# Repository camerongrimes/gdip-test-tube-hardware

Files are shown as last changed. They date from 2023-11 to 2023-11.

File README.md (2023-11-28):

# GDIP Test Tube Hardware

Controller for AL5D Lynxmotion robotic arm.

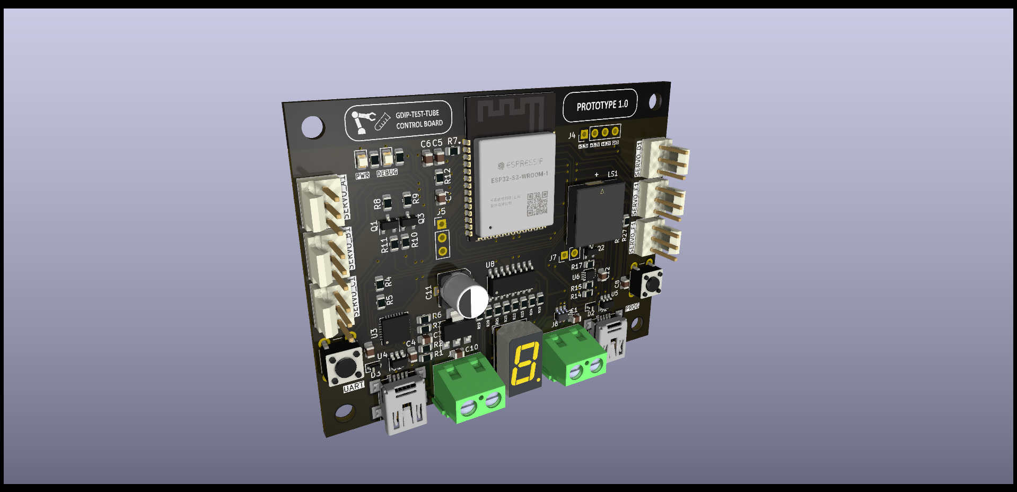
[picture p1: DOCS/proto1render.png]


## Features

- Webpage based more control using WiFi from the ESP32.
- Six servo outputs for control of all AL5D servos.
- Buzzer used to warn user that robotic arm is about to move.
- Seven segment display for error codes.
- Extra screw terminal for control of safety lightings around the arm.

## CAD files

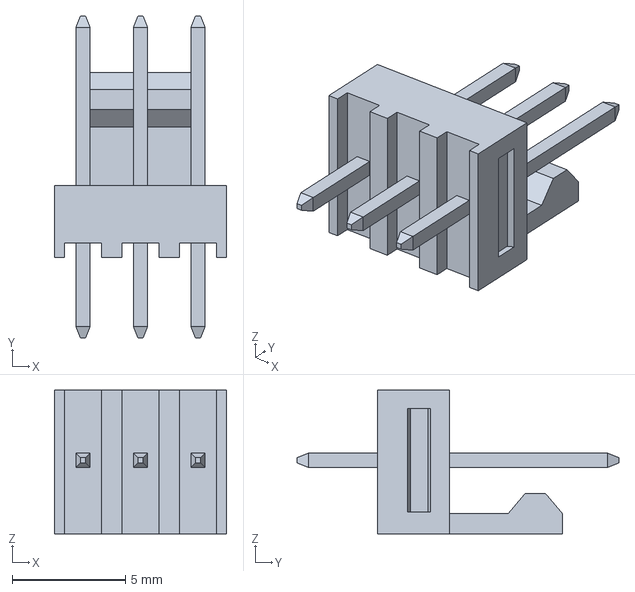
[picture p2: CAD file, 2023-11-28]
3D_MODELS/22-23-2031.stp
7.62 x 14.2 x 6.35 mm

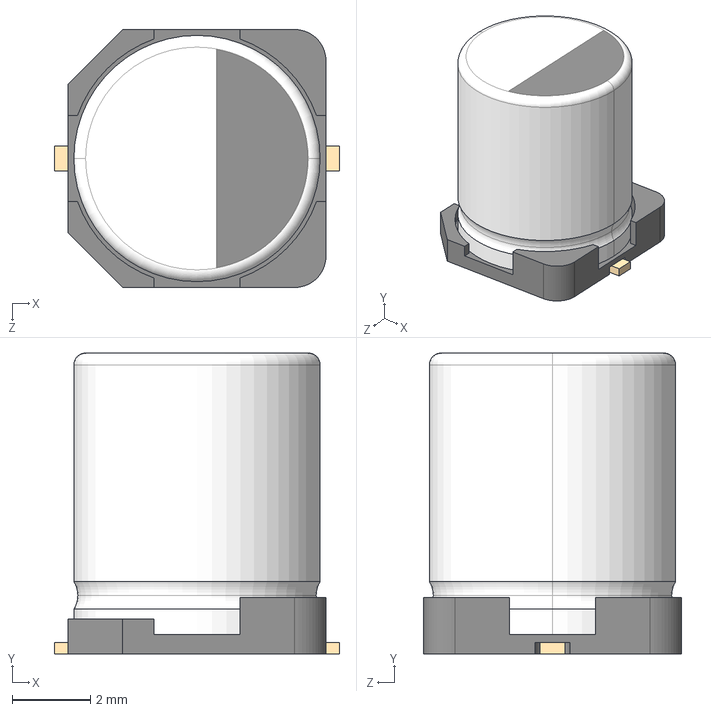
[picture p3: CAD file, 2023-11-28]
3D_MODELS/EEE-HA1H470XP.STEP
7.30 x 7.70 x 6.60 mm

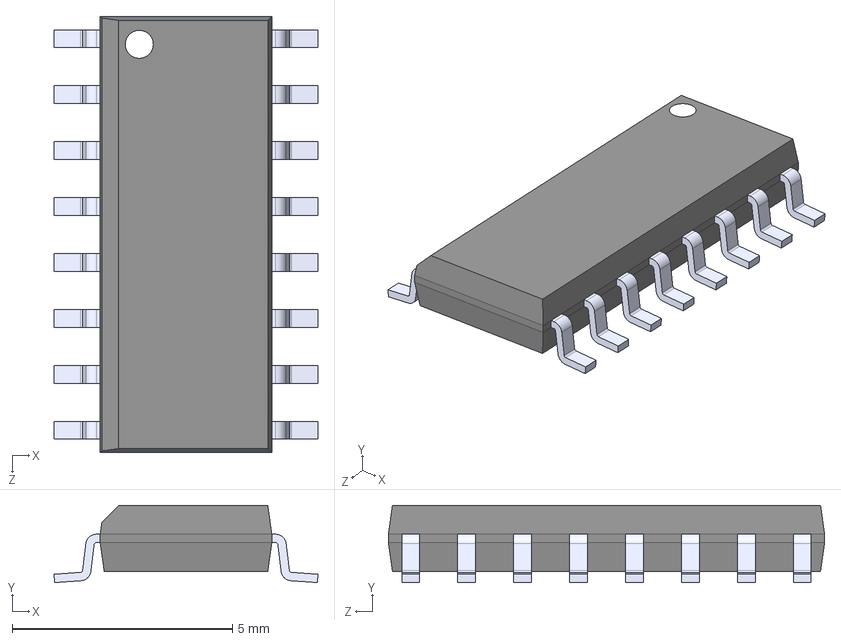
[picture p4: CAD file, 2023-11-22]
3D_MODELS/CD4543BM96.STEP
5.99 x 1.75 x 9.91 mm

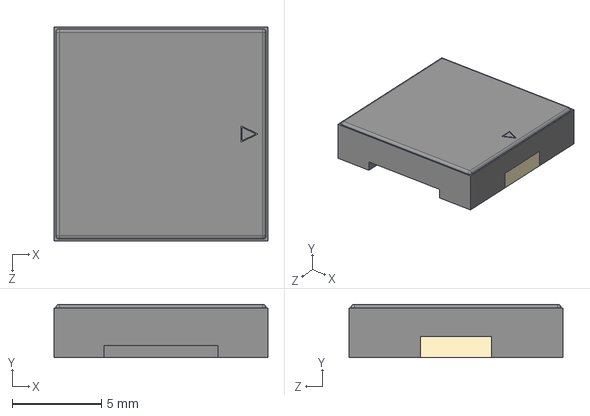
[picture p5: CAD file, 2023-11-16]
3D_MODELS/PKLCS1212E40A1-R1.STEP
12.0 x 3.00 x 12.0 mm

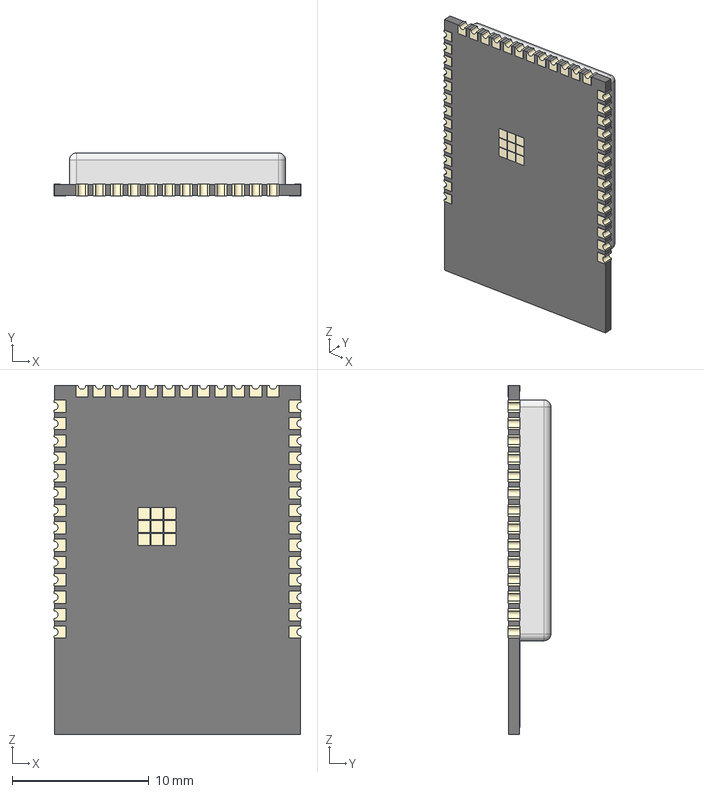
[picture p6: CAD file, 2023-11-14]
3D_MODELS/ESP32-S3-WROOM.step
18.0 x 3.16 x 25.5 mm
ESP-S3-WROOM_via x 26
ESP32-S3-WROOM_shell
ESP32-S3-WROOM_body
ESP-S3-WROOM_via v3(镜像) x 14

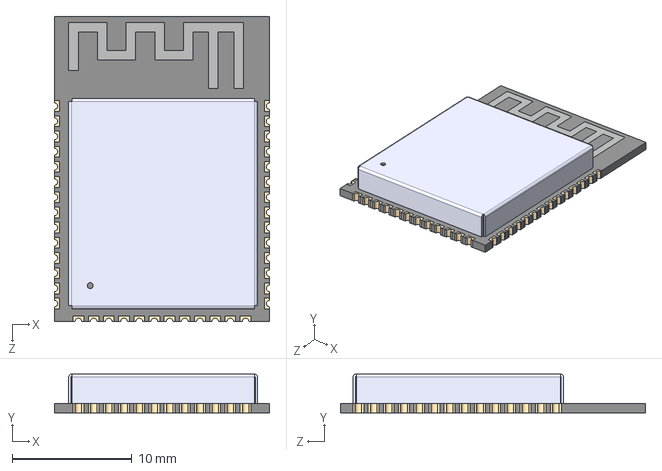
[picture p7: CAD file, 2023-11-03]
3D_MODELS/ESP32-S3-WROOM-1-N16R2.step
18.0 x 3.25 x 25.5 mm

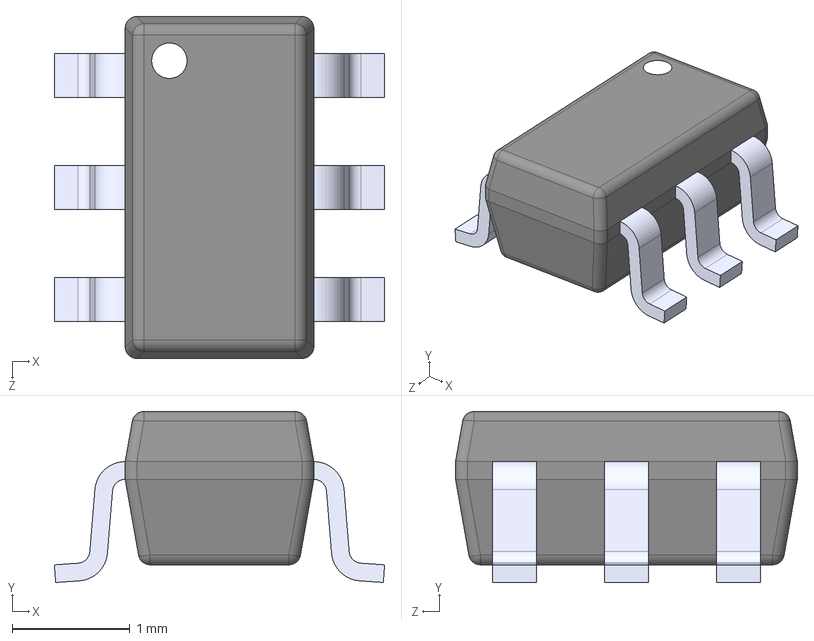
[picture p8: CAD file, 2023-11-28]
3D_MODELS/TPS22810DBVT.step
2.80 x 1.45 x 2.90 mm

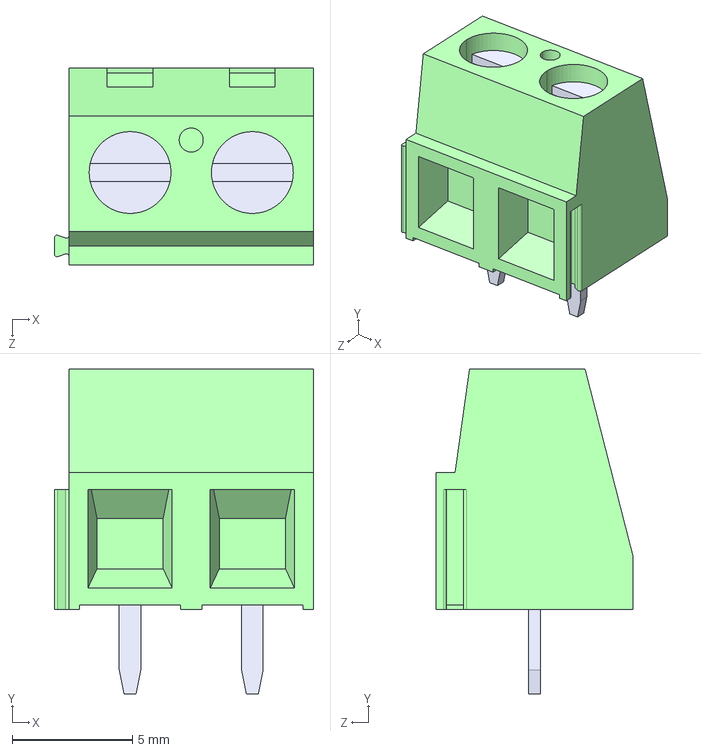
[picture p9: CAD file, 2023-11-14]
3D_MODELS/282837-2--3DModel-STEP-269445.STEP
10.8 x 13.5 x 8.20 mm

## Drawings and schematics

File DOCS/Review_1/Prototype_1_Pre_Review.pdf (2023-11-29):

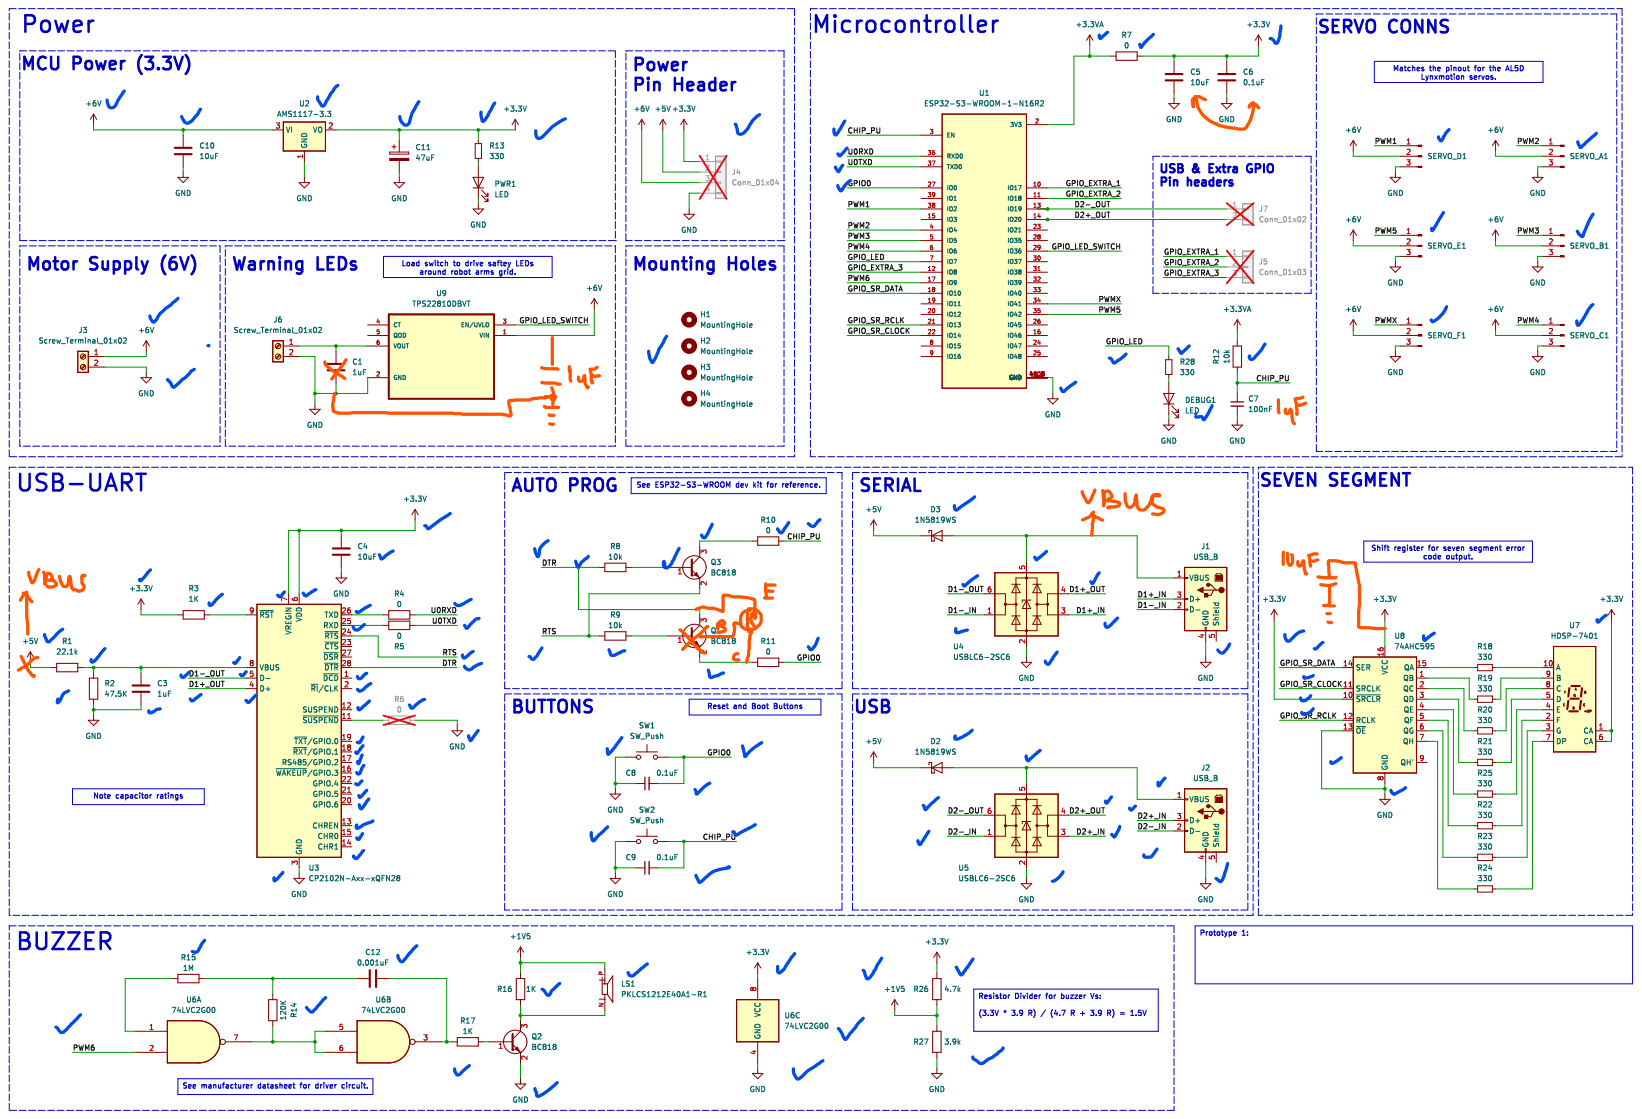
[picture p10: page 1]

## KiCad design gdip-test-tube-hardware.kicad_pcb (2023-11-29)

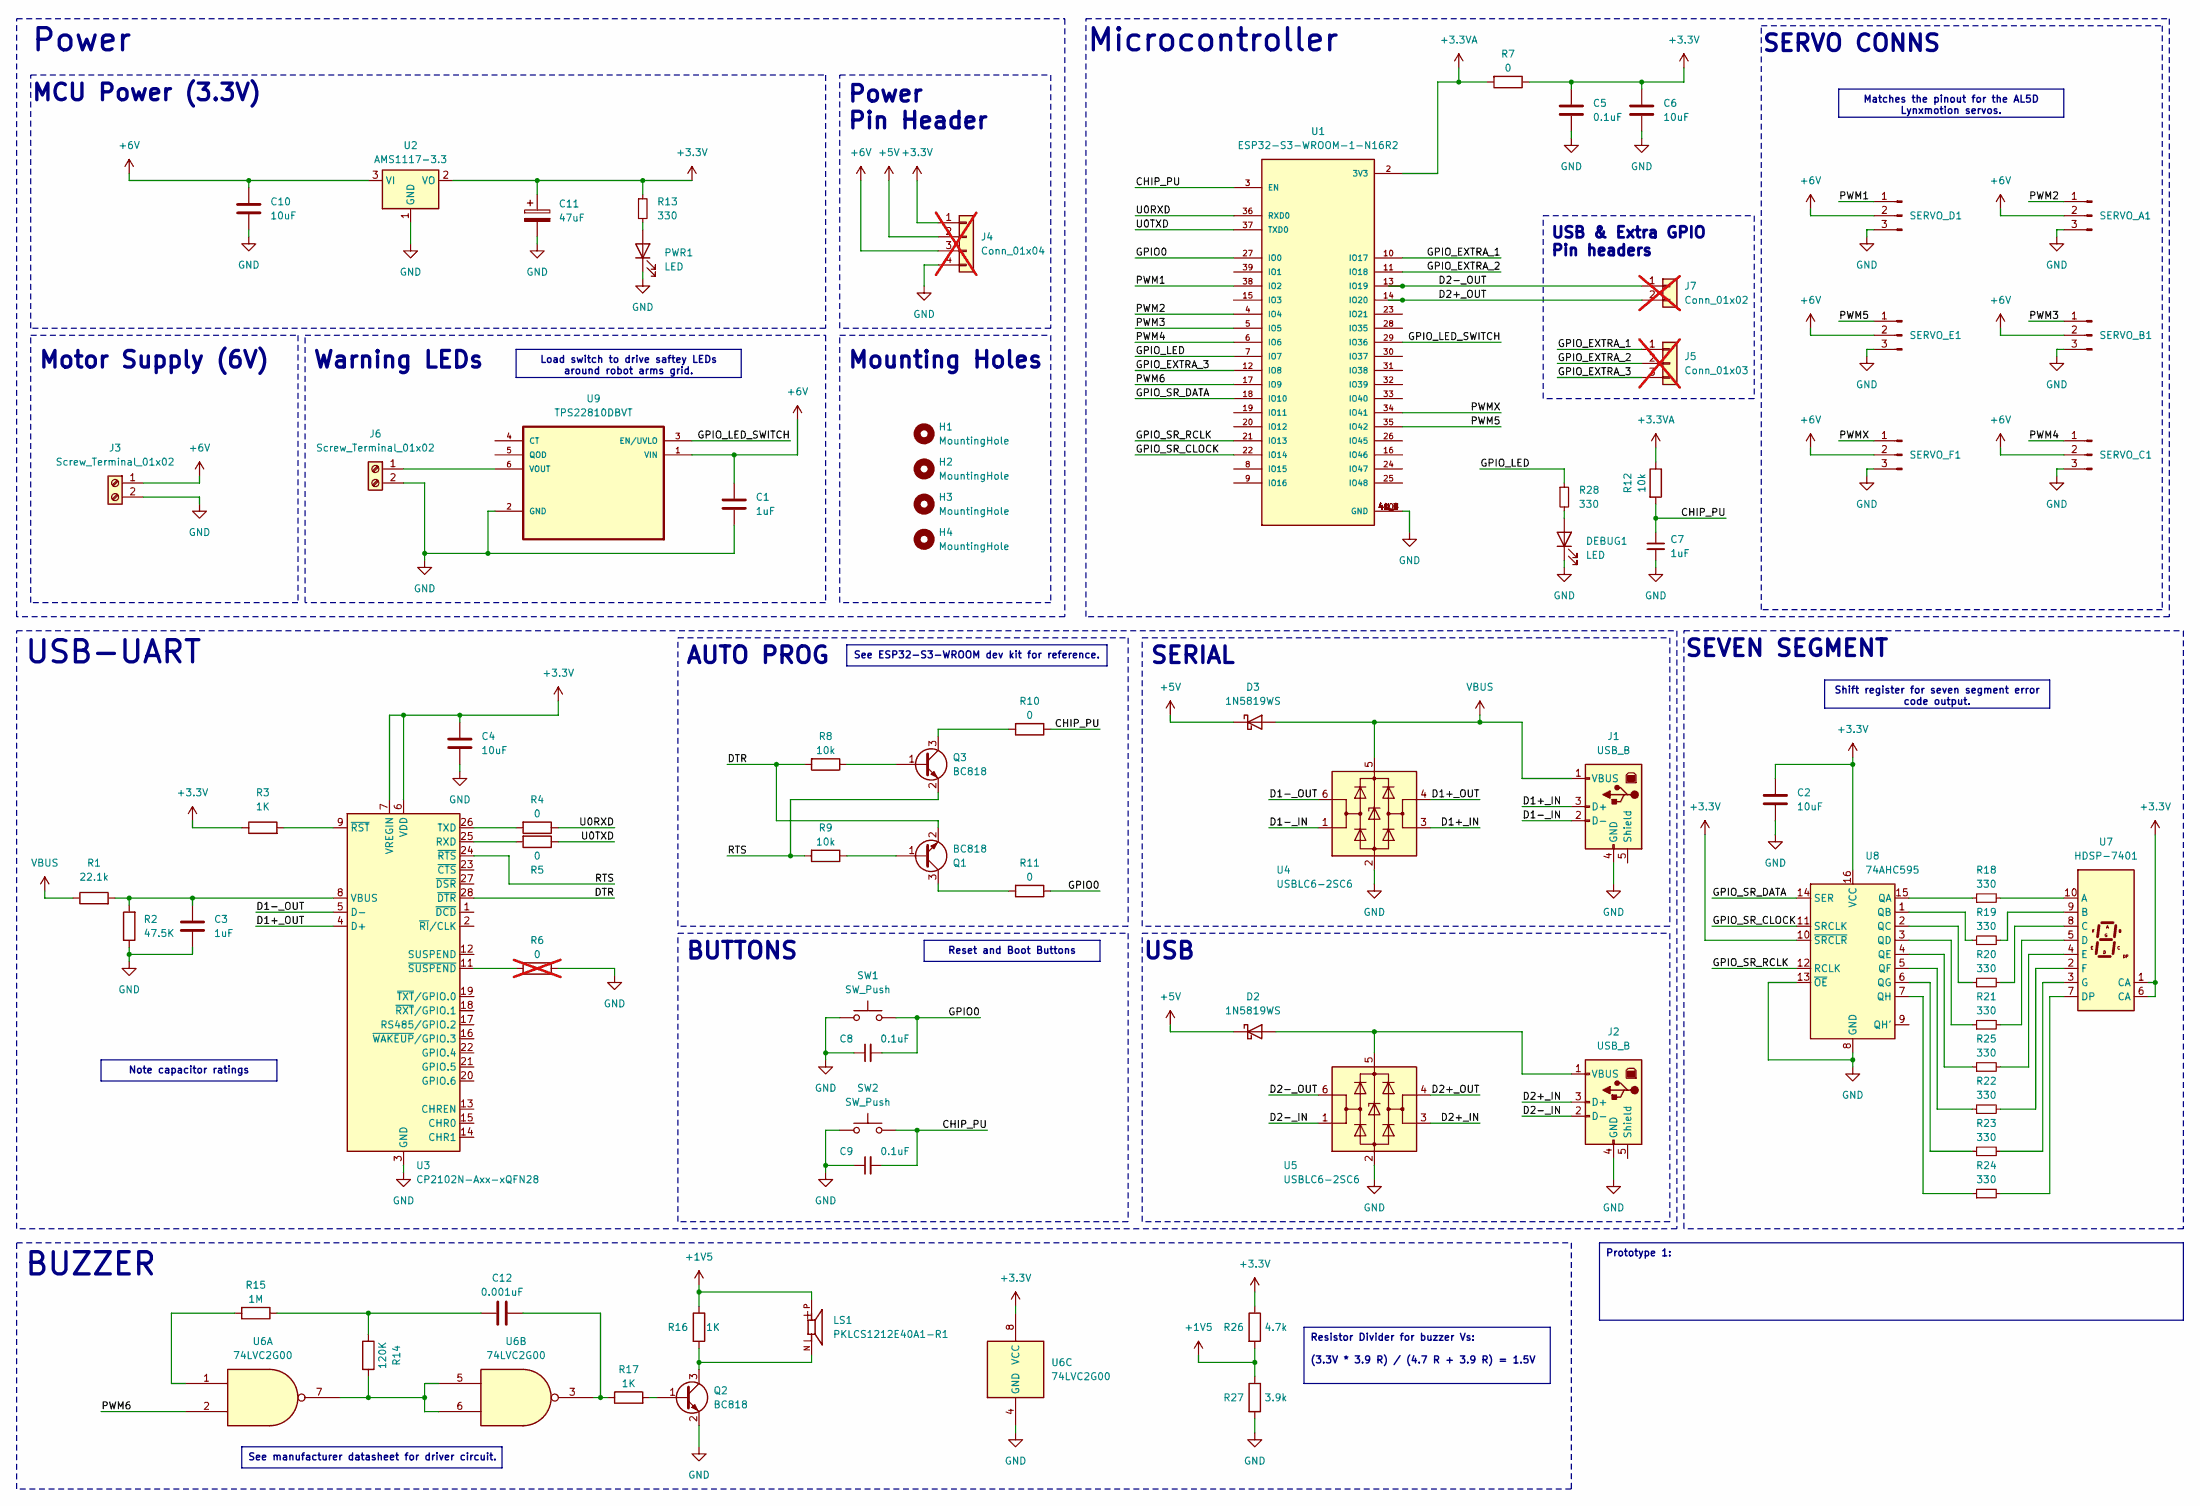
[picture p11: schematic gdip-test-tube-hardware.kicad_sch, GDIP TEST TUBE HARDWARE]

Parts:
C1, C3, C7: 1uF; C_0805_2012Metric
C2, C4, C6, C10: 10uF; C_0805_2012Metric
C5, C8, C9: 0.1uF; C_0805_2012Metric
C11: 47uF; CAP_EEEHA1H470XP
C12: 0.001uF; C_0805_2012Metric
D2, D3: 1N5819WS; D_SOD-323
DEBUG1: LED; LED_0805_2012Metric
H1, H2, H3, H4: MountingHole; MountingHole_3.5mm
J1, J2: USB_B; USB_Mini-B_Wuerth_65100516121_Horizontal
J3, J6: Screw_Terminal_01x02; TE_282837-2
J4: Conn_01x04; PinHeader_1x04_P2.54mm_Vertical; not fitted
J5: Conn_01x03; PinHeader_1x03_P2.54mm_Vertical; not fitted
J7: Conn_01x02; PinHeader_1x02_P2.54mm_Vertical; not fitted
LS1: PKLCS1212E40A1-R1; SPKR_PKLCS1212E40A1-R1; PARTREV January 22, 2018
PWR1: LED; LED_0805_2012Metric
Q1, Q2, Q3: BC818; SOT-23
R1: 22.1k; R_0805_2012Metric
R2: 47.5K; R_0805_2012Metric
R3, R16, R17: 1K; R_0805_2012Metric
R4, R5, R7, R10, R11: 0; R_0805_2012Metric
R6: 0; R_0805_2012Metric; not fitted
R8, R9, R12: 10k; R_0805_2012Metric
R13, R18, R19, R20, R21, R22, R23, R24, R25, R28: 330; R_0805_2012Metric
R14: 120K; R_0805_2012Metric
R15: 1M; R_0805_2012Metric
R26: 4.7k; R_0805_2012Metric
R27: 3.9k; R_0805_2012Metric
SERVO_A1: Conn_01x03_Pin; FanPinHeader_1x03_P2.54mm_Vertical
SERVO_B1: Conn_01x03_Pin; FanPinHeader_1x03_P2.54mm_Vertical
SERVO_C1: Conn_01x03_Pin; FanPinHeader_1x03_P2.54mm_Vertical
SERVO_D1: Conn_01x03_Pin; FanPinHeader_1x03_P2.54mm_Vertical
SERVO_E1: Conn_01x03_Pin; FanPinHeader_1x03_P2.54mm_Vertical
SERVO_F1: Conn_01x03_Pin; FanPinHeader_1x03_P2.54mm_Vertical
SW1, SW2: SW_Push; SW_PUSH_6mm
U1: ESP32-S3-WROOM-1-N16R2; XCVR_ESP32-S3-WROOM-1-N16R2; PARTREV v1.0
U2: AMS1117-3.3; SOT-223-3_TabPin2
U3: CP2102N-Axx-xQFN28; QFN-28-1EP_5x5mm_P0.5mm_EP3.35x3.35mm
U4: USBLC6-2SC6; SOT-23-6; JLCPCB C2687116
U5: USBLC6-2SC6; SOT-23-6
U6: 74LVC2G00; VSSOP-8_2.4x2.1mm_P0.5mm
U7: HDSP-7401
U8: 74AHC595; SOIC-16_3.9x9.9mm_P1.27mm
U9: TPS22810DBVT; SOT95P280X145-6N

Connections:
+1V5: LS1.P, R16.1, R26.2, R27.1
+3.3V: C2.1, C4.1, C5.1, C6.1, C11.1, J4.1, R3.1, R7.1, R13.1, R26.1, U2.2 (VO), U3.6 (VDD), U3.7 (VREGIN), U6.8 (VCC), U7.1 (CA), U7.6 (CA), U8.10 (~SRCLR), U8.16 (VCC)
+3.3VA: R7.2, R12.1, U1.2 (3V3)
+5V: D2.1 (K), D3.1 (K), J4.2
+6V: C1.1, C10.1, J3.1, J4.3, SERVO_A1.2, SERVO_B1.2, SERVO_C1.2, SERVO_D1.2, SERVO_E1.2, SERVO_F1.2, U2.3 (VI), U9.1 (VIN)
/CHIP_PU: C7.1, C9.2, R10.1, R12.2, SW2.2, U1.3 (EN)
/D1+_IN: J1.3 (D+), U4.3 (I/O2)
/D1+_OUT: U3.4 (D+), U4.4 (I/O2)
/D1-_IN: J1.2 (D-), U4.1 (I/O1)
/D1-_OUT: U3.5 (D-), U4.6 (I/O1)
/D2+_IN: J2.3 (D+), U5.3 (I/O2)
/D2+_OUT: J7.2, U1.14 (IO20), U5.4 (I/O2)
/D2-_IN: J2.2 (D-), U5.1 (I/O1)
/D2-_OUT: J7.1, U1.13 (IO19), U5.6 (I/O1)
/DTR: Q1.2 (E), R8.2, U3.28 (~DTR)
/GPIO0: C8.2, R11.1, SW1.2, U1.27 (IO0)
/GPIO_EXTRA_1: J5.1, U1.10 (IO17)
/GPIO_EXTRA_2: J5.2, U1.11 (IO18)
/GPIO_EXTRA_3: J5.3, U1.12 (IO8)
/GPIO_LED: R28.1, U1.7 (IO7)
/GPIO_LED_SWITCH: U1.29 (IO36), U9.3 (EN/UVLO)
/GPIO_SR_CLOCK: U1.22 (IO14), U8.11 (SRCLK)
/GPIO_SR_DATA: U1.18 (IO10), U8.14 (SER)
/GPIO_SR_RCLK: U1.21 (IO13), U8.12 (RCLK)
/PWM1: SERVO_D1.1, U1.38 (IO2)
/PWM2: SERVO_A1.1, U1.4 (IO4)
/PWM3: SERVO_B1.1, U1.5 (IO5)
/PWM4: SERVO_C1.1, U1.6 (IO6)
/PWM5: SERVO_E1.1, U1.35 (IO42)
/PWM6: U1.17 (IO9), U6.2
/PWMX: SERVO_F1.1, U1.34 (IO41)
/RTS: Q3.2 (E), R9.2, U3.24 (~RTS)
/U0RXD: R4.1, U1.36 (RXD0)
/U0TXD: R5.1, U1.37 (TXD0)
GND: C1.2, C2.2, C3.2, C4.2, C5.2, C6.2, C7.2, C8.1, C9.1, C10.2, C11.2, DEBUG1.1 (K), J1.4 (GND), J2.4 (GND), J3.2, J4.4, J6.2, PWR1.1 (K), Q2.2 (E), R2.1, R6.1, R27.2, SERVO_A1.3, SERVO_B1.3, SERVO_C1.3, SERVO_D1.3, SERVO_E1.3, SERVO_F1.3, SW1.1, SW2.1, U1.1 (GND), U1.40 (GND), U1.41_1 (GND), U1.41_2 (GND), U1.41_3 (GND), U1.41_4 (GND), U1.41_5 (GND), U1.41_6 (GND), U1.41_7 (GND), U1.41_8 (GND), U1.41_9 (GND), U2.1 (GND), U3.3 (GND), U3.29 (GND), U4.2 (GND), U5.2 (GND), U6.4 (GND), U8.8 (GND), U8.13 (~OE), U9.2 (GND)
unnamed: C12.1, R14.1, R15.1
unnamed: C12.2, R17.1, U6.3
unnamed: D2.2 (A), J2.1 (VBUS), U5.5 (VBUS)
unnamed: DEBUG1.2 (A), R28.2
unnamed: J6.1, U9.6 (VOUT)
unnamed: PWR1.2 (A), R13.2
unnamed: Q1.1 (B), R9.1
unnamed: Q1.3 (C), R11.2
unnamed: Q2.1 (B), R17.2
unnamed: LS1.N, Q2.3 (C), R16.2
unnamed: Q3.1 (B), R8.1
unnamed: Q3.3 (C), R10.2
unnamed: R14.2, U6.5, U6.6, U6.7
unnamed: R15.2, U6.1
unnamed: R5.2, U3.25 (RXD)
unnamed: R4.2, U3.26 (TXD)
unnamed: C3.1, R1.2, R2.2, U3.8 (VBUS)
unnamed: R3.2, U3.9 (~RST)
unnamed: R6.2, U3.11 (~SUSPEND)
unnamed: R18.2, U7.10 (A)
unnamed: R19.2, U7.9 (B)
unnamed: R20.2, U7.8 (C)
unnamed: R21.2, U7.5 (D)
unnamed: R24.2, U7.7 (DP)
unnamed: R25.2, U7.4 (E)
unnamed: R22.2, U7.2 (F)
unnamed: R23.2, U7.3 (G)
unnamed: R18.1, U8.15 (QA)
unnamed: R19.1, U8.1 (QB)
unnamed: R20.1, U8.2 (QC)
unnamed: R21.1, U8.3 (QD)
unnamed: R25.1, U8.4 (QE)
unnamed: R22.1, U8.5 (QF)
unnamed: R23.1, U8.6 (QG)
unnamed: R24.1, U8.7 (QH)
VBUS: D3.2 (A), J1.1 (VBUS), R1.1, U4.5 (VBUS)

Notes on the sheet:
Shift register for seven segment error code output.
Matches the pinout for the AL5D Lynxmotion servos.
Load switch to drive saftey LEDs around robot arms grid.
Prototype 1:
Note capacitor ratings
Resistor Divider for buzzer Vs: (3.3V * 3.9 R) / (4.7 R + 3.9 R) = 1.5V
See ESP32-S3-WROOM dev kit for reference.
Reset and Boot Buttons
See manufacturer datasheet for driver circuit.
BUZZER
SERVO CONNS
SERIAL
USB
SEVEN SEGMENT
Microcontroller
Mounting Holes
AUTO PROG
Power Pin Header
Motor Supply (6V)
Warning LEDs
BUTTONS
Power
MCU Power (3.3V)
USB-UART
USB & Extra GPIO Pin headers

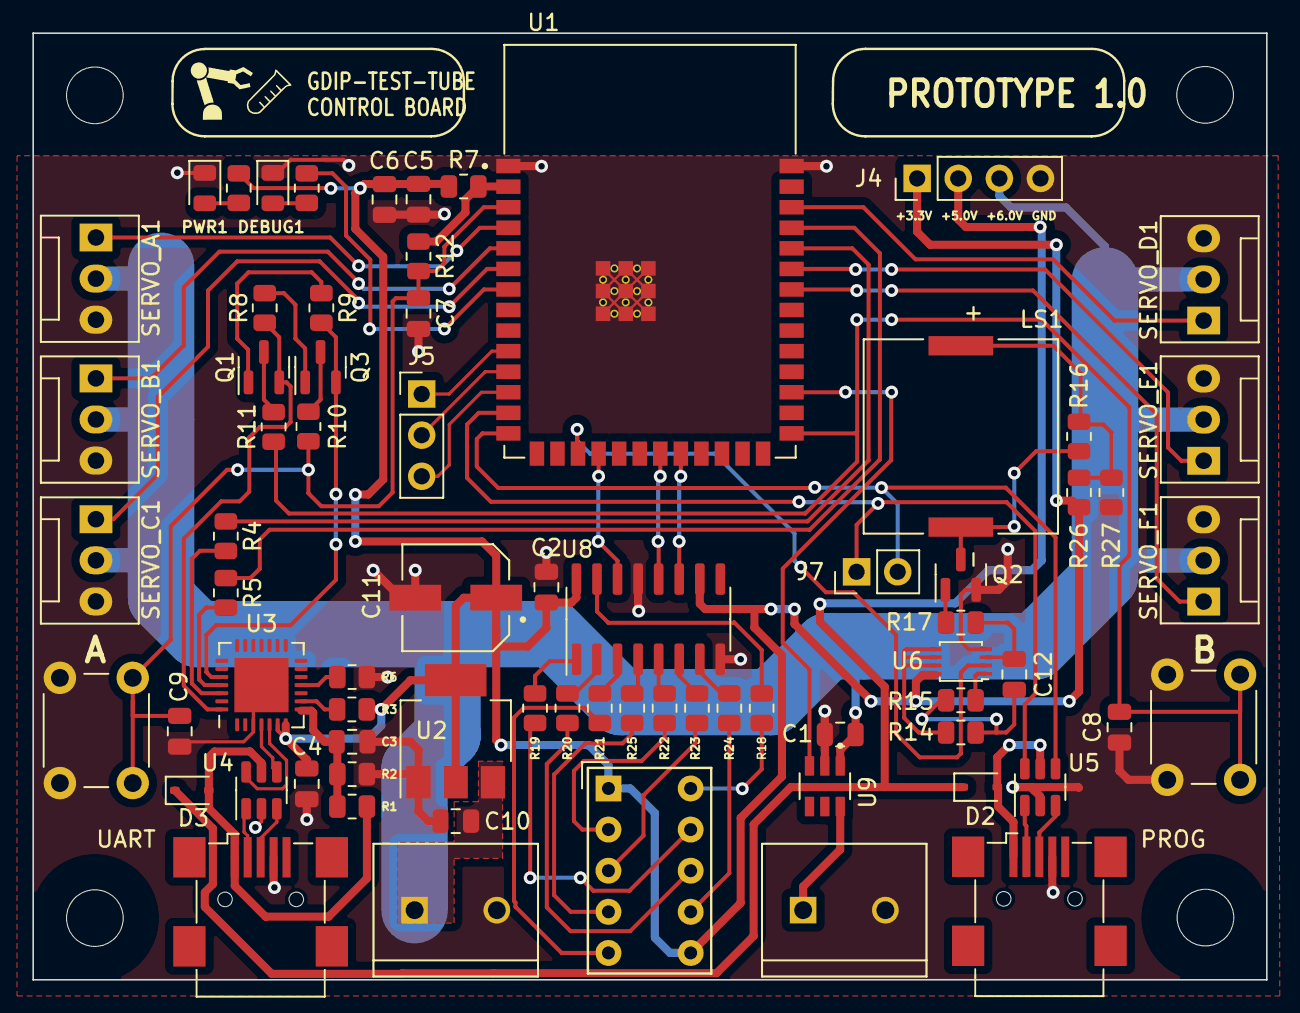
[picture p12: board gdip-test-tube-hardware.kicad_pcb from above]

Board: 2 copper layers, 76.2 x 58.5 mm, 76 parts (0 on the bottom side), 71 nets.

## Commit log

2023-11-03 Added local lib for symbols and footprints. Added ESP32-S3-WROOM and folder for step models.
    [ESP32-S3-WROOM-1-N16R2.step]
2023-11-05 Added in USB-UART IC
2023-11-07 Started adding in USB & ESD protection,
    [gdip-test-tube-hardware.kicad_sch]
2023-11-14 Added connections for servo and finshed up usb-serial ic.
    [gdip-test-tube-hardware.kicad_sch]
2023-11-14 Added auto prog circuit.
    [gdip-test-tube-hardware.kicad_sch]
2023-11-14 Added pinout and connect pwm to servo pin header.
    [gdip-test-tube-hardware.kicad_sch]
2023-11-14 Finshed switch cricuit for prog.
    [gdip-test-tube-hardware.kicad_sch]
2023-11-14 Added caps for 3.3V reg and added nets for motor power supply.
    [gdip-test-tube-hardware.kicad_sch]
2023-11-14 Added LED for power supply indication.
    [gdip-test-tube-hardware.kicad_sch]
2023-11-14 Started inital layout, board with correct height and width, and main components placed.
    [282837-2--3DModel-STEP-269445.STEP, ESP32-S3-WROOM.step, gdip-test-tube-hardware.kicad_pcb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]
2023-11-16 Added buzzer circuit in.
    [PKLCS1212E40A1-R1.STEP, gdip-test-tube-hardware.kicad_pcb, gdip-test-tube-hardware.kicad_sch]
2023-11-22 Removed multiplexer for buzzer and servo as we can remap any ESP32 pin. Also switched mux for shift register for the 7-seg display.
    [CD4543BM96.STEP, gdip-test-tube-hardware.kicad_pcb, gdip-test-tube-hardware.kicad_sch]
2023-11-27 Further work on layout.
    [gdip-test-tube-hardware.kicad_pcb, gdip-test-tube-hardware.kicad_sch]
2023-11-28 Finished first layout added load switch for led saftey circuit,changed 47uF cap footprint. Also added extra pin headers for USB, Voltages & Gnd on board and extra GPIOs.
    [EEE-HA1H470XP.STEP, TPS22810DBVT.step, gdip-test-tube-hardware.kicad_pcb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]
2023-11-28 Cleaned up files. Also have no DRC errors, had to make some changes to ESP32 thermal ties as they would not be within JLCPCB specs for a 2 layer board, hole size and pad were increased.
    [gdip-test-tube-hardware.kicad_pcb]
2023-11-28 Moved PWR led and added a DEBUG led in better locations. Also tested the step file of a molex part for servro headers.
    [22-23-2031.stp, gdip-test-tube-hardware.kicad_pcb, gdip-test-tube-hardware.kicad_sch]
2023-11-29 Reviewed schematic and made changes please view docs folder for more info. Schematic now complete.
    [Reviews.xlsx, gdip-test-tube-hardware.kicad_pcb, gdip-test-tube-hardware.kicad_sch]
2023-11-29 Inital DRC check all complete, now doing final run over.
    [gdip-test-tube-hardware.kicad_pcb]
